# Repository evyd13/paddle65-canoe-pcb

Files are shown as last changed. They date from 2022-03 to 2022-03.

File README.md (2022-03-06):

# Paddle65

***This PCB design has not been tested yet***

Paddle65 Canoe replacement PCB

## About
The Paddle65 is a no-frills replacement PCB for the Canoe (gen 1) by Percent Studios. It should fit the case without any modifications.

## Manufacturing
You know the drill ;)

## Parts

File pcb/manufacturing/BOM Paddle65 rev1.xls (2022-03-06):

Paddle65 rev1 BOM
Manufacturer | Manufacturer Part Number (required) | Designator (required) | Qty (required) | Description (required) | Case | SMD ,BGA,LCC,OR TH | Top/Bottom | points (number of contacts the IC has in each board) | Total points (number of contacts per BOM line has) | Comment
Samsung Electro-Mechanics | CL21B104KBCNNNC | C1-C4, C7, C8 | 6 | 100nf capacitor | 0805 | SMD | Bottom
Samsung Electro-Mechanics | CL21A106KOQNNNE | C5 | 1 | 10uf capacitor | 0805 | SMD | Bottom
Samsung Electro-Mechanics | CL21A105KBCLNNC | C6 | 1 | 1uf capacitor | 0805 | SMD | Bottom
LIZ Elec | CD4148WSP | D1-D63, D67, D70-D75 | 70 | Switching diode | 0805 | SMD | Bottom
Walsin Tech Corp | WR08X103JTL | R3, R4 | 2 | 10k ohm resistor | 0805 | SMD | Bottom
Walsin Tech Corp | WR08X220JTL | R1, R2 | 2 | 22 ohm resistor | 0805 | SMD | Bottom
Walsin Tech Corp | WR08X471JTL | R5, R6 | 2 | 470 ohm resistor | 0805 | SMD | Bottom
Microchip Tech | ATMEGA32U4-AU | U1 | 1 | Microcontroller | QFP-44 | SMD | Bottom |  |  | Do not substitute
STMicroelectronics | USBLC6-2SC6 | U2 | 1 | Diode ESD | SOT-23-6 | SMD | Bottom |  |  | Do not substitute
Korean Hroparts Elec | K2-1187SQ-A4SW-06 | SW1 | 1 | Tactile switch |  | SMD | Bottom
Murata Electronics | CSTNE16M0V530000R0 | X1 | 1 | 16 MHz Resonator |  | SMD | Bottom |  |  | Do not substitute
TLC Electronic | TLC-PSMD050 | F1 | 1 | PTC Fuse; 500mAh hold, 1A trip | 0805 | SMD | Bottom |  |  | Do not substitute
Hirose | UX60SC-MB-5S8 | J1 | 1 | Mini USB connector |  | SMD+TH | Top |  |  | Do not substitute
DONGGUAN OPSCO OPTOELECTRONICS | SK6812MINI-E | RGB1, RGB2 | 2 | Addressable RGB LED |  | SMD | Bottom

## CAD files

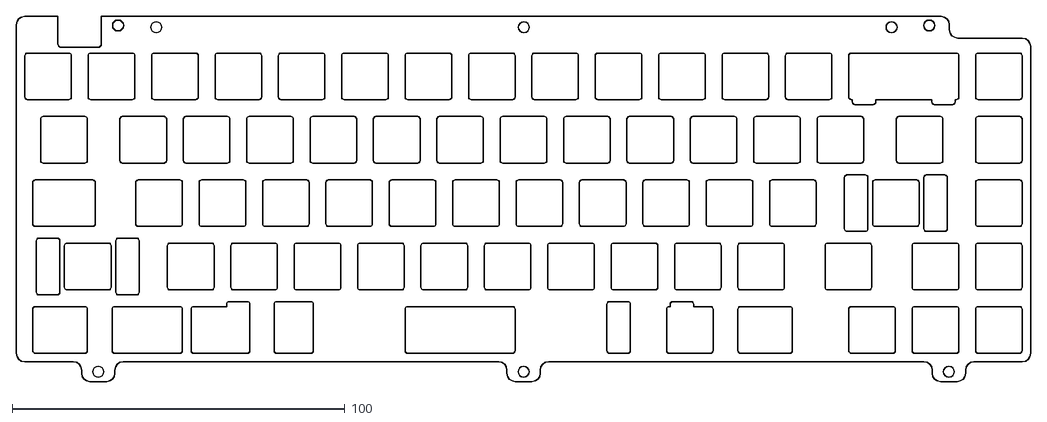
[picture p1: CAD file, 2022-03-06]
plate/plate_ansi.dxf
304.8 x 109.8

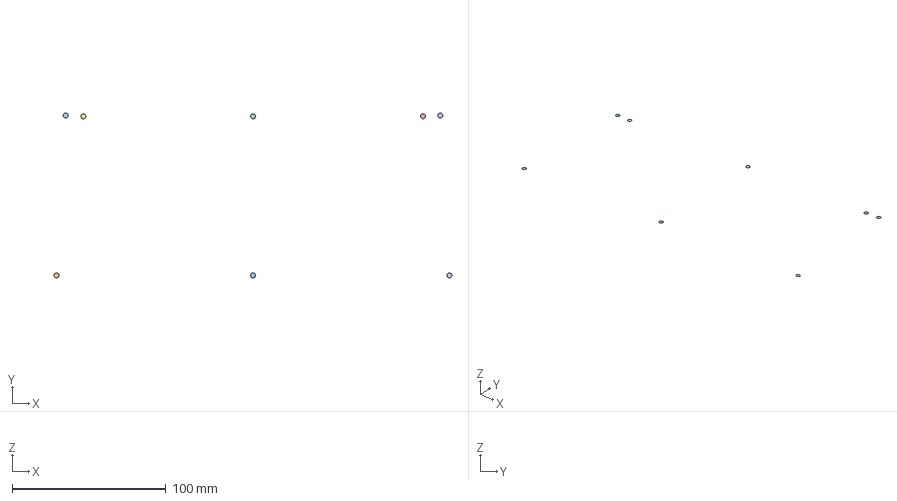
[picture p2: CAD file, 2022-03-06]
plate/plate.FCStd
259.0 x 107.3 x 0 mm
Circle
Circle001
Circle002
Circle003
Circle004
Circle005
Circle006
Circle007

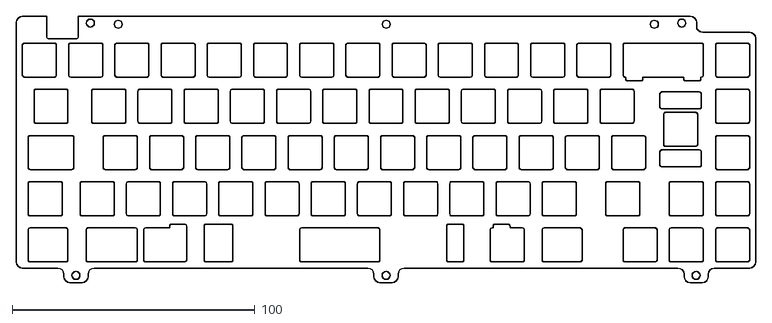
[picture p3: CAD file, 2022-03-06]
plate/plate_iso.dxf
304.8 x 109.8

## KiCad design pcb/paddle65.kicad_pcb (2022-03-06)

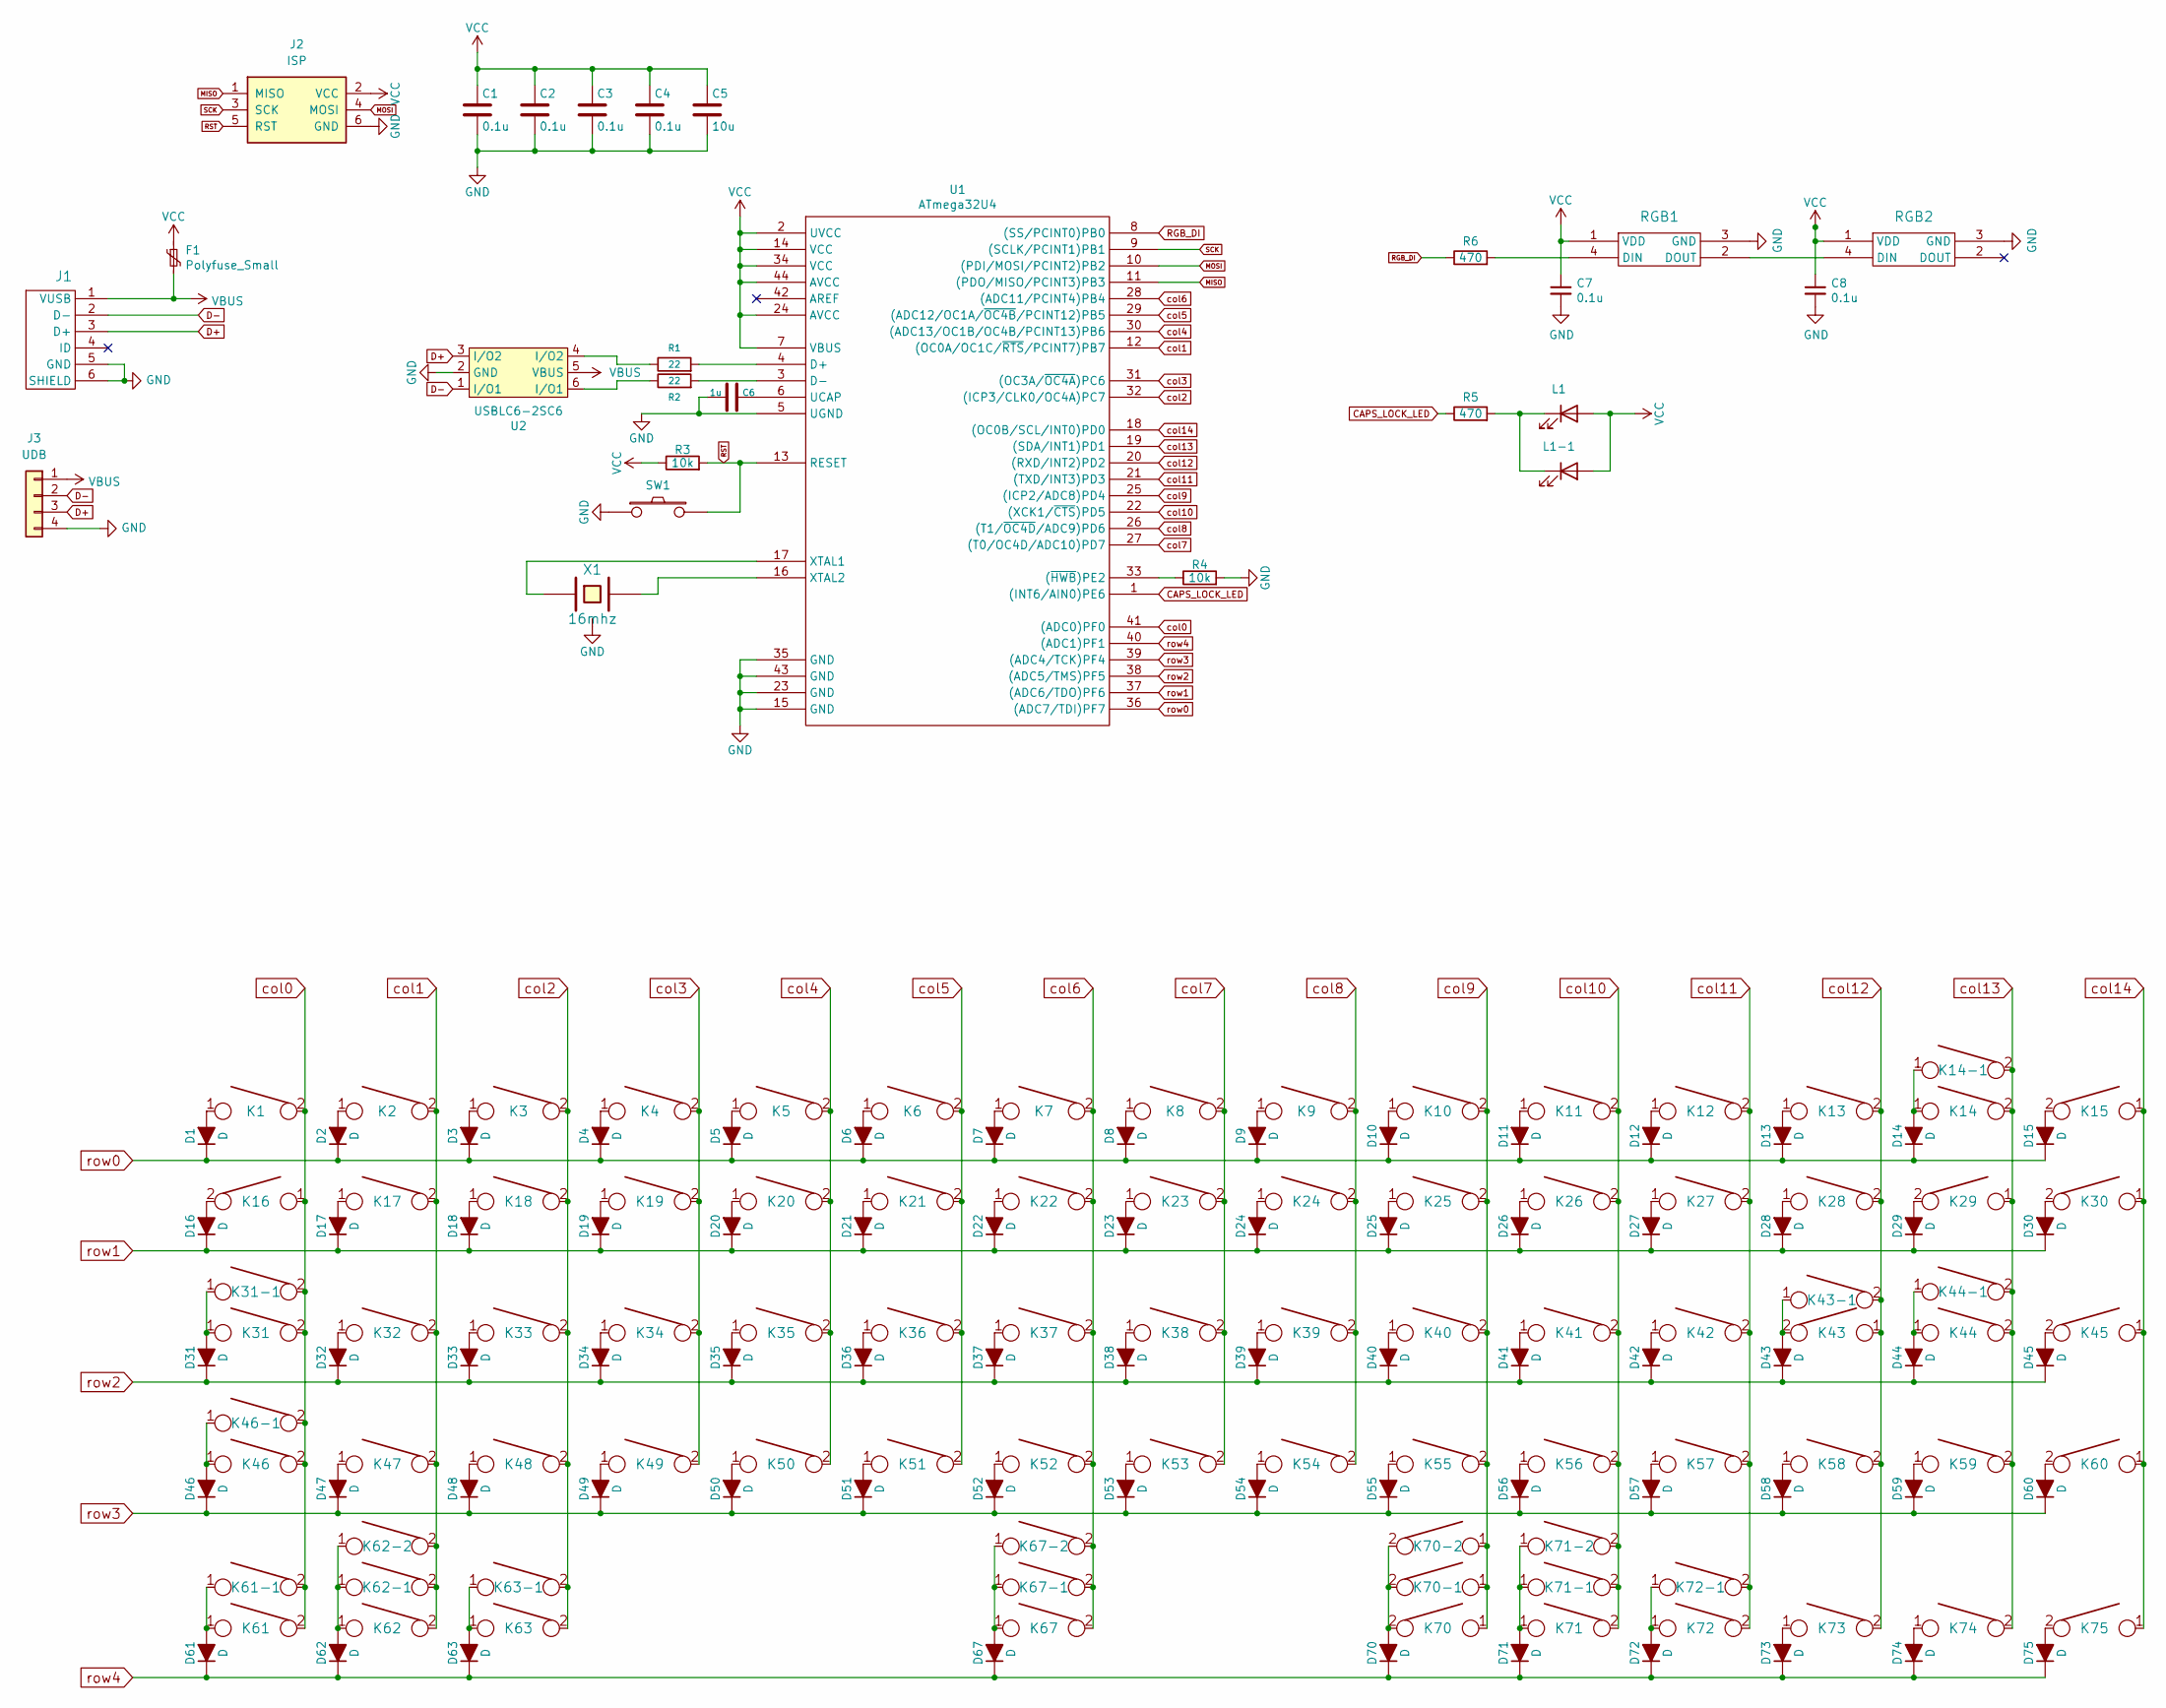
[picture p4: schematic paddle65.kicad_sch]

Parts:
C1, C2, C3, C4, C7, C8: 0.1u; C_0805
C5: 10u; C_0805
C6: 1u; C_0805
D1, D2, D3, D4, D5, D6, D7, D8, D9, D10, D11, D12, D13, D14, D15, D16, D17, D18, D19, D20, D21, D22, D23, D24, D25, D26, D27, D28, D29, D30, D31, D32, D33, D34, D35, D36, D37, D38, D39, D40, D41, D42, D43, D44, D45, D46, D47, D48, D49, D50, D51, D52, D53, D54, D55, D56, D57, D58, D59, D60, D61, D62, D63, D67, D70, D71, D72, D73, D74, D75: D; D_0805
F1: Polyfuse_Small; R_0805
J1: USB_mini_micro_B; CONN_UX60SC-MB-5S8
J2: ISP; CONN_isp_standard
J3: UDB; CONN_JST_SH_SM04B-SRSS-TB_1x04-1MP_P1.00mm_Horizontal
K1, K2, K3, K4, K5, K6, K7, K8, K9, K10, K11, K12, K13, K14-1, K15, K17, K18, K19, K20, K21, K22, K23, K24, K25, K26, K27, K28, K29, K30, K32, K33, K34, K35, K36, K37, K38, K39, K40, K41, K42, K43, K45, K47, K48, K49, K50, K51, K52, K53, K54, K55, K56, K57, K59, K60, K62-1, K70-1, K71-2, K72, K73, K74, K75: KEYSW; CHERRY_PLATE_100H
K14: KEYSW; CHERRY_PCB_200H
K16, K43-1, K61-1, K62-2, K63-1, K70-2, K71-1, K72-1: KEYSW; CHERRY_PLATE_150H
K31, K58: KEYSW; CHERRY_PLATE_175H
K31-1, K46-1, K61, K62, K63, K70, K71: KEYSW; CHERRY_PLATE_125H
K44, K46: KEYSW; CHERRY_PCB_225H
K44-1: KEYSW; CHERRY_PCB_200H_V
K67: KEYSW; CHERRY_PCB_625H_F
K67-1, K67-2: KEYSW; CHERRY_PCB_700H_F
L1, L1-1: LED; CHERRY_MX_LED_neo
R1, R2: 22; R_0805
R3, R4: 10k; R_0805
R5, R6: 470; R_0805
RGB1, RGB2: SK6812MINI-E; LED_SK6812MINI-E
SW1: SW_PUSH; SWITCH_SPST_TL3342
U1: ATmega32U4; MCU_ATMEGA32U4-AU
U2: USBLC6-2SC6; PACKAGE_SOT-23-6
X1: 16mhz; XTAL_SMD_Murata_CSTxExxV-3Pin_3.0x1.1mm

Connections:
CAPS_LOCK_LED: R5.1, U1.1 ((INT6/AIN0)PE6)
D+: J1.3 (D+), J3.3, U2.3 (I/O2)
D-: J1.2 (D-), J3.2, U2.1 (I/O1)
GND: C1.2, C2.2, C3.2, C4.2, C5.2, C6.2, C7.2, C8.2, J1.5 (GND), J1.6 (SHIELD), J2.6 (GND), J3.4, R4.2, RGB1.3 (GND), RGB2.3 (GND), SW1.1, U1.5 (UGND), U1.15 (GND), U1.23 (GND), U1.35 (GND), U1.43 (GND), U2.2 (GND), X1.3
MISO: J2.1 (MISO), U1.11 ((PDO/MISO/PCINT3)PB3)
MOSI: J2.4 (MOSI), U1.10 ((PDI/MOSI/PCINT2)PB2)
unnamed: C6.1, U1.6 (UCAP)
unnamed: D1.2 (A), K1.1
unnamed: D2.2 (A), K2.1
unnamed: D3.2 (A), K3.1
unnamed: D4.2 (A), K4.1
unnamed: D5.2 (A), K5.1
unnamed: D6.2 (A), K6.1
unnamed: D7.2 (A), K7.1
unnamed: D8.2 (A), K8.1
unnamed: D9.2 (A), K9.1
unnamed: D10.2 (A), K10.1
unnamed: D11.2 (A), K11.1
unnamed: D12.2 (A), K12.1
unnamed: D13.2 (A), K13.1
unnamed: D14.2 (A), K14.1, K14-1.1
unnamed: D15.2 (A), K15.2
unnamed: D16.2 (A), K16.2
unnamed: D17.2 (A), K17.1
unnamed: D18.2 (A), K18.1
unnamed: D19.2 (A), K19.1
unnamed: D20.2 (A), K20.1
unnamed: D21.2 (A), K21.1
unnamed: D22.2 (A), K22.1
unnamed: D23.2 (A), K23.1
unnamed: D24.2 (A), K24.1
unnamed: D25.2 (A), K25.1
unnamed: D26.2 (A), K26.1
unnamed: D27.2 (A), K27.1
unnamed: D28.2 (A), K28.1
unnamed: D29.2 (A), K29.2
unnamed: D30.2 (A), K30.2
unnamed: D31.2 (A), K31.1, K31-1.1
unnamed: D32.2 (A), K32.1
unnamed: D33.2 (A), K33.1
unnamed: D34.2 (A), K34.1
unnamed: D35.2 (A), K35.1
unnamed: D36.2 (A), K36.1
unnamed: D37.2 (A), K37.1
unnamed: D38.2 (A), K38.1
unnamed: D39.2 (A), K39.1
unnamed: D40.2 (A), K40.1
unnamed: D41.2 (A), K41.1
unnamed: D42.2 (A), K42.1
unnamed: D43.2 (A), K43.2, K43-1.1
unnamed: D44.2 (A), K44.1, K44-1.1
unnamed: D45.2 (A), K45.2
unnamed: D46.2 (A), K46.1, K46-1.1
unnamed: D47.2 (A), K47.1
unnamed: D48.2 (A), K48.1
unnamed: D49.2 (A), K49.1
unnamed: D50.2 (A), K50.1
unnamed: D51.2 (A), K51.1
unnamed: D52.2 (A), K52.1
unnamed: D53.2 (A), K53.1
unnamed: D54.2 (A), K54.1
unnamed: D55.2 (A), K55.1
unnamed: D56.2 (A), K56.1
unnamed: D57.2 (A), K57.1
unnamed: D58.2 (A), K58.1
unnamed: D59.2 (A), K59.1
unnamed: D60.2 (A), K60.2
unnamed: D61.2 (A), K61.1, K61-1.1
unnamed: D62.2 (A), K62.1, K62-1.1, K62-2.1
unnamed: D63.2 (A), K63.1, K63-1.1
unnamed: D67.2 (A), K67.1, K67-1.1, K67-2.1
unnamed: D70.2 (A), K70.2, K70-1.2, K70-2.2
unnamed: D71.2 (A), K71.1, K71-1.1, K71-2.1
unnamed: D72.2 (A), K72.1, K72-1.1
unnamed: D73.2 (A), K73.1
unnamed: D74.2 (A), K74.1
unnamed: D75.2 (A), K75.2
unnamed: L1.1 (K), L1-1.1 (K), R5.2
unnamed: R1.1, U2.4 (I/O2)
unnamed: R1.2, U1.4 (D+)
unnamed: R2.1, U2.6 (I/O1)
unnamed: R2.2, U1.3 (D-)
unnamed: R4.1, U1.33 ((~HWB)PE2)
unnamed: R6.2, RGB1.4 (DIN)
unnamed: RGB1.2 (DOUT), RGB2.4 (DIN)
unnamed: U1.16 (XTAL2), X1.2
unnamed: U1.17 (XTAL1), X1.1
RGB_DI: R6.1, U1.8 ((SS/PCINT0)PB0)
RST: J2.5 (RST), R3.2, SW1.2, U1.13 (RESET)
SCK: J2.3 (SCK), U1.9 ((SCLK/PCINT1)PB1)
VBUS: F1.2, J1.1 (VUSB), J3.1, U2.5 (VBUS)
VCC: C1.1, C2.1, C3.1, C4.1, C5.1, C7.1, C8.1, F1.1, J2.2 (VCC), L1.2 (A), L1-1.2 (A), R3.1, RGB1.1 (VDD), RGB2.1 (VDD), U1.2 (UVCC), U1.7 (VBUS), U1.14 (VCC), U1.24 (AVCC), U1.34 (VCC), U1.44 (AVCC)
col0: K1.2, K16.1, K31.2, K31-1.2, K46.2, K46-1.2, K61.2, K61-1.2, U1.41 ((ADC0)PF0)
col1: K2.2, K17.2, K32.2, K47.2, K62.2, K62-1.2, K62-2.2, U1.12 ((OC0A/OC1C/~RTS/PCINT7)PB7)
col2: K3.2, K18.2, K33.2, K48.2, K63.2, K63-1.2, U1.32 ((ICP3/CLK0/OC4A)PC7)
col3: K4.2, K19.2, K34.2, K49.2, U1.31 ((OC3A/~OC4A)PC6)
col4: K5.2, K20.2, K35.2, K50.2, U1.30 ((ADC13/OC1B/OC4B/PCINT13)PB6)
col5: K6.2, K21.2, K36.2, K51.2, U1.29 ((ADC12/OC1A/~OC4B/PCINT12)PB5)
col6: K7.2, K22.2, K37.2, K52.2, K67.2, K67-1.2, K67-2.2, U1.28 ((ADC11/PCINT4)PB4)
col7: K8.2, K23.2, K38.2, K53.2, U1.27 ((T0/OC4D/ADC10)PD7)
col8: K9.2, K24.2, K39.2, K54.2, U1.26 ((T1/~OC4D/ADC9)PD6)
col9: K10.2, K25.2, K40.2, K55.2, K70.1, K70-1.1, K70-2.1, U1.25 ((ICP2/ADC8)PD4)
col10: K11.2, K26.2, K41.2, K56.2, K71.2, K71-1.2, K71-2.2, U1.22 ((XCK1/~CTS)PD5)
col11: K12.2, K27.2, K42.2, K57.2, K72.2, K72-1.2, U1.21 ((TXD/INT3)PD3)
col12: K13.2, K28.2, K43.1, K43-1.2, K58.2, K73.2, U1.20 ((RXD/INT2)PD2)
col13: K14.2, K14-1.2, K29.1, K44.2, K44-1.2, K59.2, K74.2, U1.19 ((SDA/INT1)PD1)
col14: K15.1, K30.1, K45.1, K60.1, K75.1, U1.18 ((OC0B/SCL/INT0)PD0)
row0: D1.1 (K), D2.1 (K), D3.1 (K), D4.1 (K), D5.1 (K), D6.1 (K), D7.1 (K), D8.1 (K), D9.1 (K), D10.1 (K), D11.1 (K), D12.1 (K), D13.1 (K), D14.1 (K), D15.1 (K), U1.36 ((ADC7/TDI)PF7)
row1: D16.1 (K), D17.1 (K), D18.1 (K), D19.1 (K), D20.1 (K), D21.1 (K), D22.1 (K), D23.1 (K), D24.1 (K), D25.1 (K), D26.1 (K), D27.1 (K), D28.1 (K), D29.1 (K), D30.1 (K), U1.37 ((ADC6/TDO)PF6)
row2: D31.1 (K), D32.1 (K), D33.1 (K), D34.1 (K), D35.1 (K), D36.1 (K), D37.1 (K), D38.1 (K), D39.1 (K), D40.1 (K), D41.1 (K), D42.1 (K), D43.1 (K), D44.1 (K), D45.1 (K), U1.38 ((ADC5/TMS)PF5)
row3: D46.1 (K), D47.1 (K), D48.1 (K), D49.1 (K), D50.1 (K), D51.1 (K), D52.1 (K), D53.1 (K), D54.1 (K), D55.1 (K), D56.1 (K), D57.1 (K), D58.1 (K), D59.1 (K), D60.1 (K), U1.39 ((ADC4/TCK)PF4)
row4: D61.1 (K), D62.1 (K), D63.1 (K), D67.1 (K), D70.1 (K), D71.1 (K), D72.1 (K), D73.1 (K), D74.1 (K), D75.1 (K), U1.40 ((ADC1)PF1)

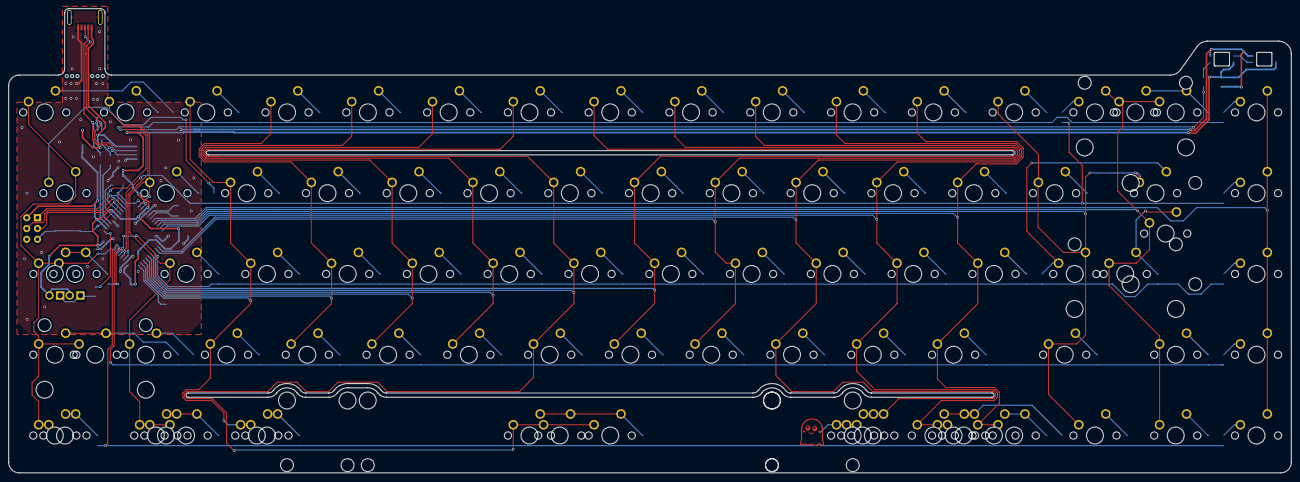
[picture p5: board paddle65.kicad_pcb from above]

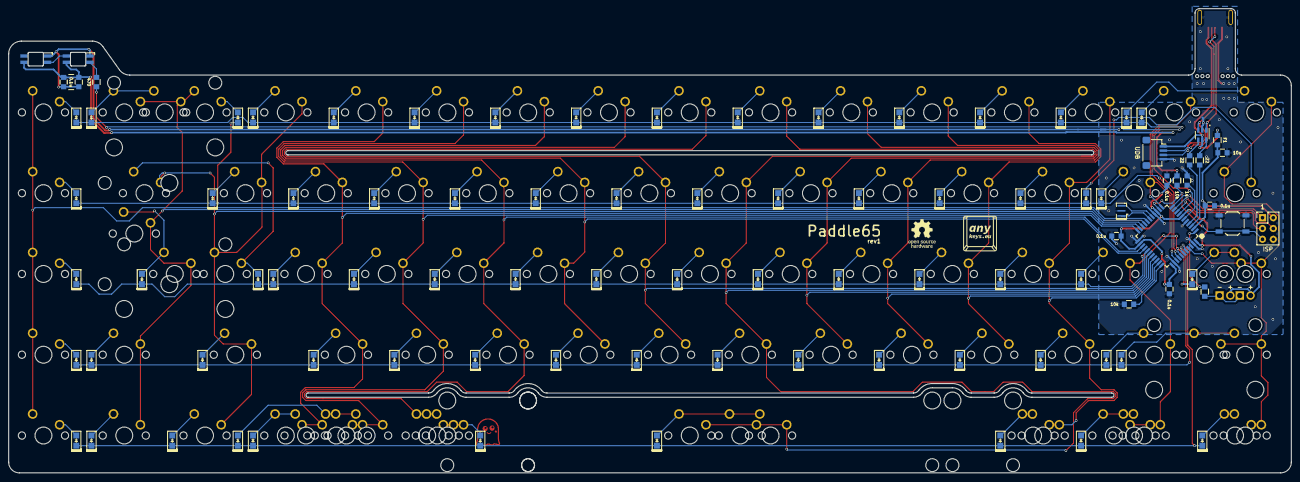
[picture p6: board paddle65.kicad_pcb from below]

Board: 2 copper layers, 302.5 x 109.5 mm, 182 parts (93 on the bottom side), 112 nets.

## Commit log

2022-03-06 Upload PCB files
    [BOM Paddle65 rev1.xls, paddle65.kicad_pcb, paddle65.kicad_sch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]
2022-03-06 Add plate & small pcb fixes
    [paddle65.kicad_pcb, plate.FCStd, plate_ansi.dxf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]
